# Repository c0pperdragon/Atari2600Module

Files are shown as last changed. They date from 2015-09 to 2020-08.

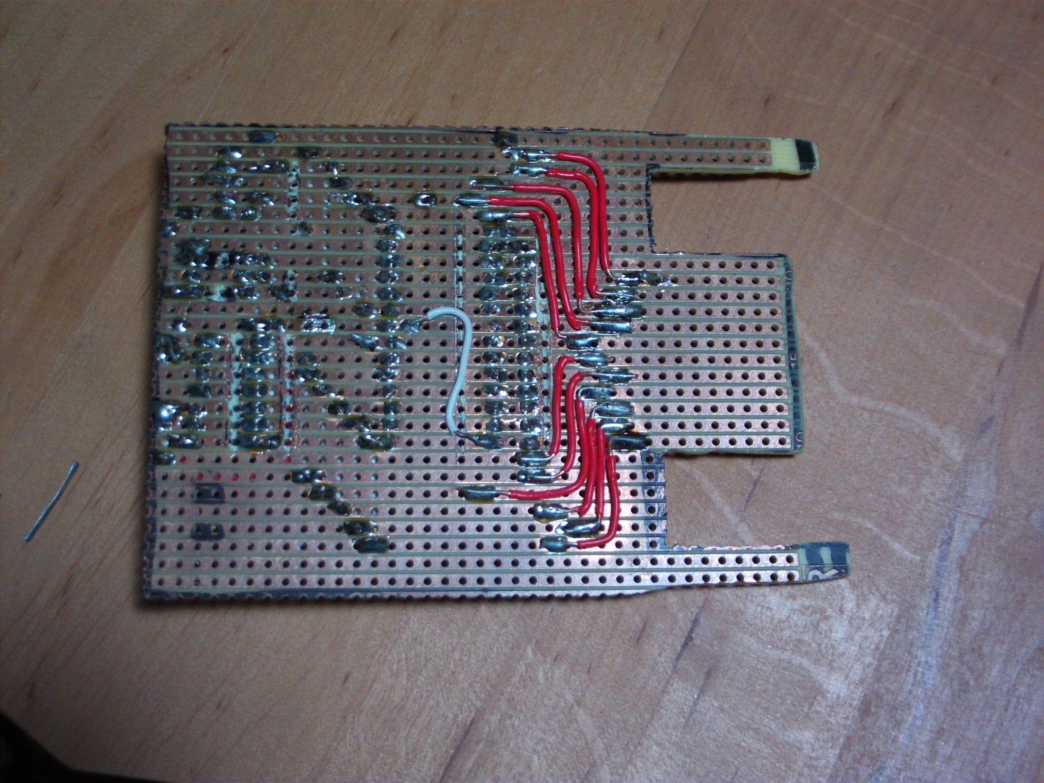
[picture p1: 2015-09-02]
gallery/backside.jpg

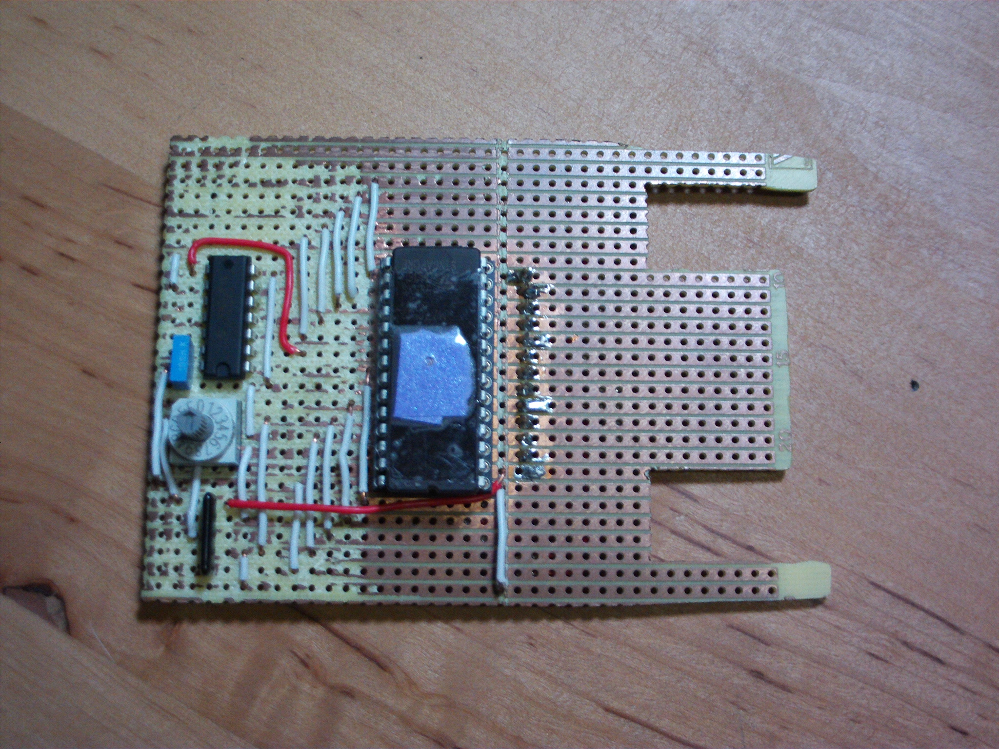
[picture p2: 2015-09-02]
gallery/cartridge.jpg

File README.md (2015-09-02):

# Atari2600Module
Game module board for Atari 2600 that can hold 16 games.

After I have obtained and repaired an old Atari 2600 console (a "light sixer" PAL variant), 
I also wanted to use it with the top games of the time. Working game cartridges can still be found
on action platforms, but it is very difficult and expensive to get the famous ones. 
On the other hand, basically everything that was ever released for the Atari 2600 is available 
as rom images on the web (PAL variants included).

Since the electronics of those days was pretty easy to handle for hobbyist, making an own 
cartridge with an EPROM (can still be obtained in PID variants) and some small electronics parts
is possible for little money.

To keep it as cheap as possible, I have not created a PCB (don't have the equipment), but
used a standard board with two layers of copper lines and cut it to the proper shape with a jigsaw.
According to the sources on the topic the Atari 2600 uses a not-inverted signal to access the 
chip select line of the EPROM, so an inverter is also on the board.
The EPROM I found was a 64KByte variant, so it could hold 16 of the standard-sized 4 KByte 
game ROMs. Selecting is done with an 16-position encoder switch that directly drives the 
higher 4 address lines of the EPROM.

One of the greatest problems in this project was to burn the EPROM. It seems that EPROMs have
completely gone out of use this days and the programmers that can still be bought are extremely
expensive. For this one-off programming I have used my Arduino Micro with one additional 8-bit 
shift register to do the job. I improvised everything on breadboards for the task. Unfortunately 
I have no schematics or images of this left, only the programmer code is still available.

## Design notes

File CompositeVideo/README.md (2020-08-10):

# Compositive Video for the Atari 2600

This is a quick non-FPGA project to get a slightly better picture from the Atari 2600.
It tries to bypass the analog sound and video processing by directly tapping
into the digital output signals of the TIA.
The digital lines are feed trough an LVC245 buffer to get rid of all the noise and then
they are directly combined with resistors to form the composite video signal.

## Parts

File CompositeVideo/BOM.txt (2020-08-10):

Description                       Value  Size         Amount  Reference
---------------------------------------------------------------------------------------
Ceramic capacitor                  10uF  2012metric        2  C4,C10
Ceramic capacitor                 100nF  2012metric        5  C1,C2,C3,C11,C17
Ceramic capacitor                  10nF  2012metric        1  C12
Ceramic capacitor                   1nF  2012metric        2  C15,16
Resistor                           100k  2012metric        2  R17,R18
Resistor                            47k  2012metric        1  R19
Resistor                            10k  2012metric        3  R1,R2,R16
Resistor                            3k3  2012metric        1  R12
Resistor                             1k  2012metric        2  R5,R15
Resistor                             2k  2012metric        2  R6,R8
Resistor                             4k  2012metric        2  R7,R9
Resistor                            330  2012metric        2  R4,R11
Resistor                            150  2012metric        2  R22,R23
Hex inverter, schmitt trigger    74HC14  SOIC-14           1  U1
Dual high speed OpAmp          MAX4030E  SO-8              1  U2

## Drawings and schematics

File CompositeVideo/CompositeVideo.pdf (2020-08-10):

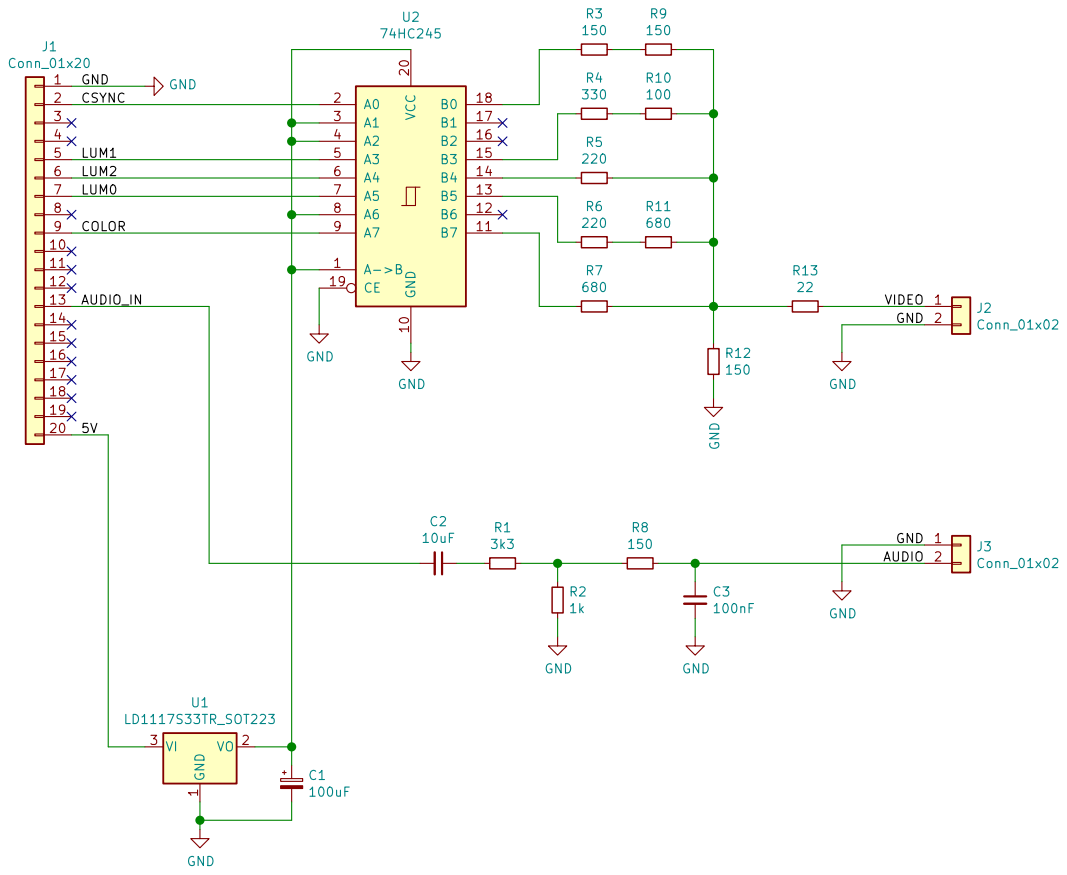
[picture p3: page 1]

AUDIO_IN GND LUM0 CSYNC 3 4 5 LUM1 | A->B 1 A0 2 A2 4 A3 5 A4 6 A5 7 A6 8 A7 9 | 11 B6 12 B5 13 B4 14 B3 15 B2 16 B1 17 B0

U2 GND 10 VCC 20 A1 3 B7 GND | 18 CE 19

GND 7

6 LUM2

8 9 COLOR

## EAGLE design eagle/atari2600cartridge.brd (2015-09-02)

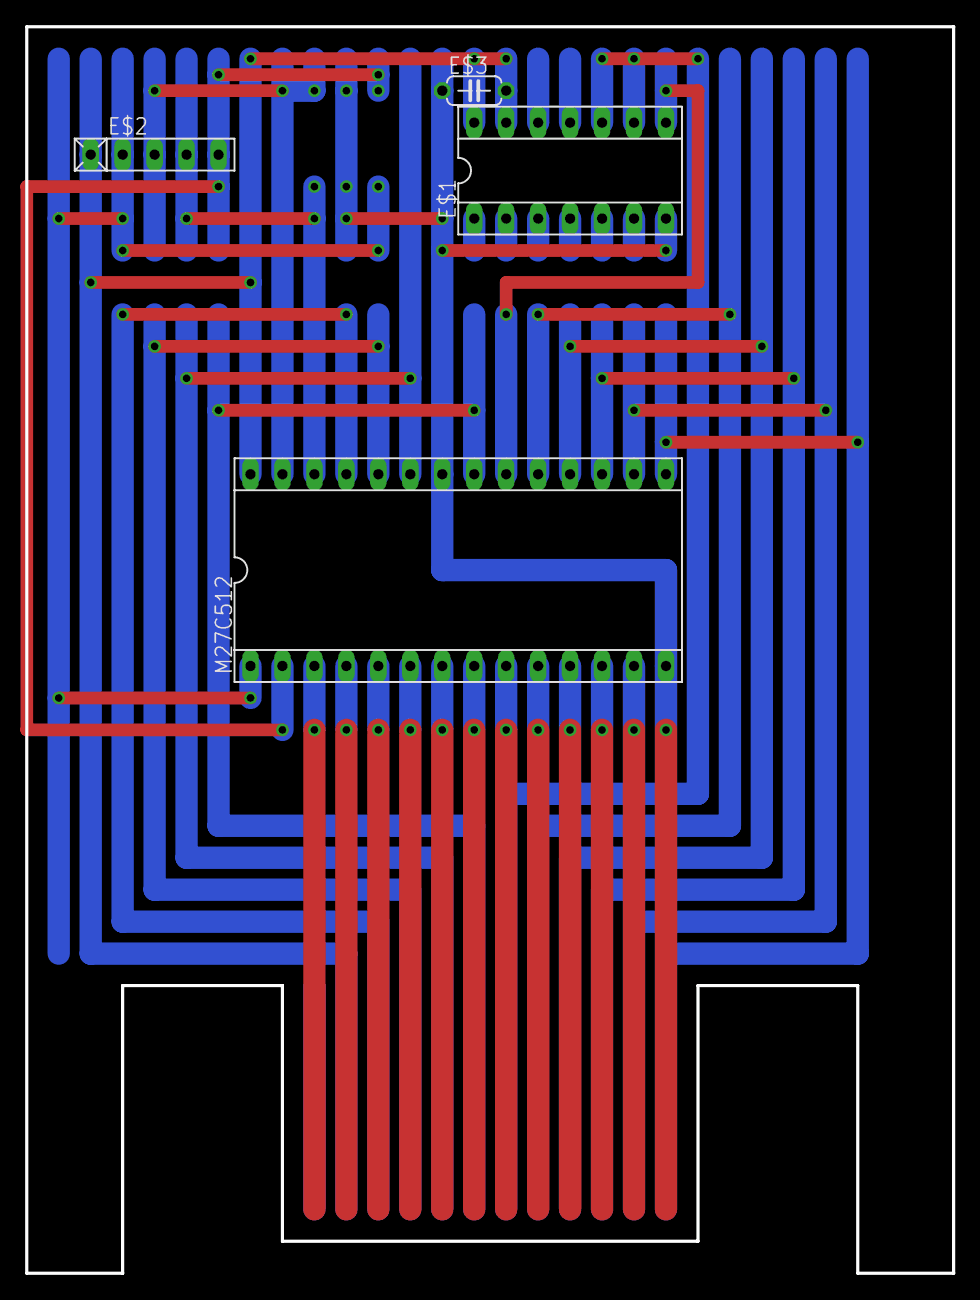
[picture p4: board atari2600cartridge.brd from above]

Board: 2 copper layers, 73.7 x 99.1 mm, 4 parts (0 on the bottom side), 8 nets.

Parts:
E$1: SOCKET-14
E$2: RN-5
E$3: C050-024X044
M27C512: SOCKET-28-6

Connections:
5V: E$1.13, E$1.14, E$2.1, E$3.2, M27C512.28
A12: E$2.5, M27C512.2
A14: E$2.3, M27C512.27
A15: E$2.2, M27C512.1
CS: E$1.9, E$1.10
E: E$1.8, M27C512.20
GND: E$1.7, E$3.1, M27C512.14, M27C512.22
S$2: E$2.4, M27C512.26

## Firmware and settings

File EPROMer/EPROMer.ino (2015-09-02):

#include <avr/pgmspace.h>

const unsigned int address = 0*4096;
const byte code[] PROGMEM = {
#include "yars_revenge_pal.h"
#include "venture_pal.h"
#include "space_invaders_pal.h"
#include "seaquest_pal.h"
};
//const unsigned int address = 4*4096;
//const byte code[] PROGMEM = {
//#include "river_raid_pal.h"
//#include "q-bert_pal.h"
//#include "pitfall_pal.h"
//#include "pac-man_pal.h"
//};
//const unsigned int address = 8*4096;
//const byte code[] PROGMEM = {
//#include "megamania_pal.h"
//#include "keystone_kapers_pal.h"
//#include "enduro_pal.h"
//#include "donkey_kong_pal.h"
//};
//const unsigned int address = 12*4096;
//const byte code[] PROGMEM = {
//#include "demon_attack_pal.h"
//#include "berzerk_pal.h"
//#include "atlantis_pal.h"
//#include "adventure_pal.h"
//};

#define E   2
#define CLK 11
#define AB  12

void setup() 
{
  pinMode(E,OUTPUT);
  digitalWrite(E,HIGH);
  pinMode(CLK,OUTPUT);
  digitalWrite(CLK,HIGH);
  pinMode(AB,OUTPUT);
  digitalWrite(AB,HIGH);

  pinMode(0,OUTPUT);
  digitalWrite(0,HIGH);
  pinMode(1,OUTPUT);
  digitalWrite(1,HIGH);
  int i;
  for (i=0; i<6; i++)
  {  pinMode(A0+i,OUTPUT);
     digitalWrite(A0+i,HIGH);
  }
  
  // let program wait until serial monitor is connected
  Serial.begin(9600);  
}


void loop() 
{
  Serial.print("EPROMer ready with ");
  Serial.print(sizeof(code));
  Serial.print(" bytes for address ");
  Serial.println(address, HEX);
  Serial.println("Valid commands: r(ead), w(rite), z(ero find) c(ompare) t(est adressing)");
  
  int c = Serial.read();
  while (c<0) c = Serial.read();
  if (c=='r')
  { 
    readeprom(false);
  }
  else if (c=='w')  
  {
    writeeprom();
  }  
  else if (c=='z')  
  {
    readeprom(true);
  }  
  else if (c=='c')  
  {
    compareeprom();
  }  
  else if (c=='t')
  { 
    testaddressanddata();
  }
}




void testaddressanddata()
{
  configureoutput();
  writeaddress(0b1000000000000000);
  writedata(0b10101010);    
}

void readeprom(bool showonlyzero)
{
  Serial.print("Reading from address: ");
  Serial.println(address);

  configureinput();
 
  long int totalzeroes = 0;
  long int i;
  for (i=0; i<0x10000; i++)
  {
    if ((i&15)==0 && !showonlyzero) {
        Serial.print(i, HEX);
        Serial.print("  ");
    }

    writeaddress(address+i);
    delayMicroseconds(1);
    digitalWrite(E, LOW);
    delayMicroseconds(1);
    
    byte d = readdata();
    digitalWrite(E, HIGH);
    
    int bit;
    for (bit=0; bit<8; bit++)
    {  
      if ((d&(1<<bit))==0) totalzeroes++;
    }
    
    if (showonlyzero)
    {
      if (d!=0xff)
      {
        Serial.print(i,HEX);  
        Serial.print(" ");
        Serial.println(d,HEX);
      }
    }
    else
    {  if (d<16) Serial.print("0");
      Serial.print(d,HEX);  
      Serial.print(" ");
      if ((i&15)==15)  Serial.print("\n");
    }
  }
  
  Serial.print("Total number of zero bits: ");
  Serial.println(totalzeroes);
}


void writeeprom()
{
  configureoutput();
  
  int len = sizeof(code);
  
  Serial.print("Programming ");
  Serial.print(len);
  Serial.print(" bytes at address ");
  Serial.println(address);

  unsigned int i;
  for (i=0; i<len; i++)
  {
    byte d = pgm_read_byte_near(code+i);

    unsigned int a = address+i;

    writeaddress(a);
    writedata(d);
    delayMicroseconds(10);
    
    int tries;
    for (tries=0; tries<50; tries++)
    { digitalWrite(E,LOW);
      delayMicroseconds(100);
      digitalWrite(E,HIGH);
      delayMicroseconds(50);
    }
    
    if (d<16) Serial.print("0");
    Serial.print(d,HEX);  
    Serial.print(" ");
    if ((i&15)==15)  Serial.print("\n");
  }
  
}


void compareeprom()
{
  configureinput();
  
  int len = sizeof(code);
  
  Serial.print("Comparing ");
  Serial.print(len);
  Serial.print(" bytes at address ");
  Serial.println(address);

  unsigned counterrors=0;
  unsigned int i;
  for (i=0; i<len; i++)
  {
    byte d = pgm_read_byte_near(code+i);

    unsigned int a = address+i;

    writeaddress(a);
    delayMicroseconds(1);
    digitalWrite(E, LOW);
    delayMicroseconds(1);    
    byte x = readdata();
    digitalWrite(E, HIGH);
    
    if (d!=x)
    {
      Serial.print("Difference at position ");      
      Serial.print(i);
      Serial.print(" (address:");
      Serial.print(a,HEX);
      Serial.print(") ");
      Serial.print(" found ");
      Serial.print(x,HEX);
      Serial.print(" instead of ");
      Serial.println(d,HEX);
      counterrors++;
    }
  }
  Serial.print("Found ");
  Serial.print(counterrors);
  Serial.println(" differences");
}




void configureoutput()
{
  int i;
  for (i=0; i<8; i++)
  {   pinMode(10-i,OUTPUT);
      digitalWrite(10-i,HIGH);
  }  
}

void configureinput()
{
  int i;
  for (i=0; i<8; i++)
  {   pinMode(10-i,INPUT);
  }  
}


// pump out bits of address serially into the shift
// registers (lowest bit comes last)
void writeaddress(unsigned int a)
{  
  int i;
  
  // two highest bits of address  
  for (i=0; i<2; i++)  
  {
    digitalWrite(1-i, ((a&0x8000) == 0) ? LOW:HIGH);  
    a = a<<1;   // continue with next bit
  }
  // next 6 bits bits of address  
  for (i=0; i<6; i++)
  {
    digitalWrite(A5-i, ((a&0x8000) == 0) ? LOW:HIGH);  
    a = a<<1;   // continue with next bit
  }
  
  // lowest 8 bit of address will be clocked into shift register
  for (i=0; i<8; i++)  
  { digitalWrite(CLK, LOW);           // prepare low-to-high transition of clock  
    digitalWrite(AB, ((a&0x8000) == 0) ? LOW:HIGH);  // put next bit to shifter input
    delayMicroseconds(1);            // let output stabilize
    digitalWrite(CLK, HIGH);          // issue clock  to shifter
    delayMicroseconds(1);            // let shifter to their work  
    a = a<<1;   // continue with next bit
  }
  digitalWrite(AB, HIGH);  // remove data from pin    
}

// put output data to the arduino pins 10 - 3 (which map to EPROM Q0 - Q7)
void writedata(unsigned int d)
{
  for (int i=0; i<8; i++)
  {  digitalWrite(10-i,((d&(1<<i))==0) ? LOW:HIGH);
  }
}

// read data from the arduino pins 10 - 3 (which map to EPROM Q0 - Q7)
byte readdata()
{
  byte d = 0;
  int i;
  for (i=0; i<8; i++)
  {
    if (digitalRead(10-i)==HIGH)
    {
      d = d | (1<<i);
    }
  }
  return d;
}

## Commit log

2015-09-02 Upload for documentary purposes
    [atari2600cartridge.brd]
2020-08-10 Circuit for compositve video from Atari 2600
    [CompositeVideo.kicad_pcb, CompositeVideo.sch]
